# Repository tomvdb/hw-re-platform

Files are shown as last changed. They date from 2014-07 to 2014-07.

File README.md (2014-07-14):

Hardware Reverse Engineering Learning Platform
==============================================

Current Status:

2014/07/17: Boards received, concept works, pcb has some minor issues. Working on v2
2014/06/20: PCB's sent for manufacturing - Not Tested Yet

I enjoy trying to reverse engineer the famous crackme and reverseme executables in my spare time. After reading the xbox reverse engineering book by bunnie I went looking at the my options for learning and experimenting with hardware reverse engineering. Unfortunately the options are few and expensive.

The hardware reverse engineering platform is basically a shield for the new stm32 nucleo boards using the st-morpho connectors. It contains two arduino compatible microcontrollers and an eeprom. There are 8 data lines connected between the two microcontrollers and there is also i2c lines connecting the mcu's with an eeprom. The nucleo board handles loading the reverse engineering scenario on the shield (firmware on the avr's and data on the eeprom). Test pins are added on all the data lines for connection to RE tools. This allows anyone to easily create firmware that depicts a possible RE situation. For example the two mcu's can communicate with each other using a certain protocol.

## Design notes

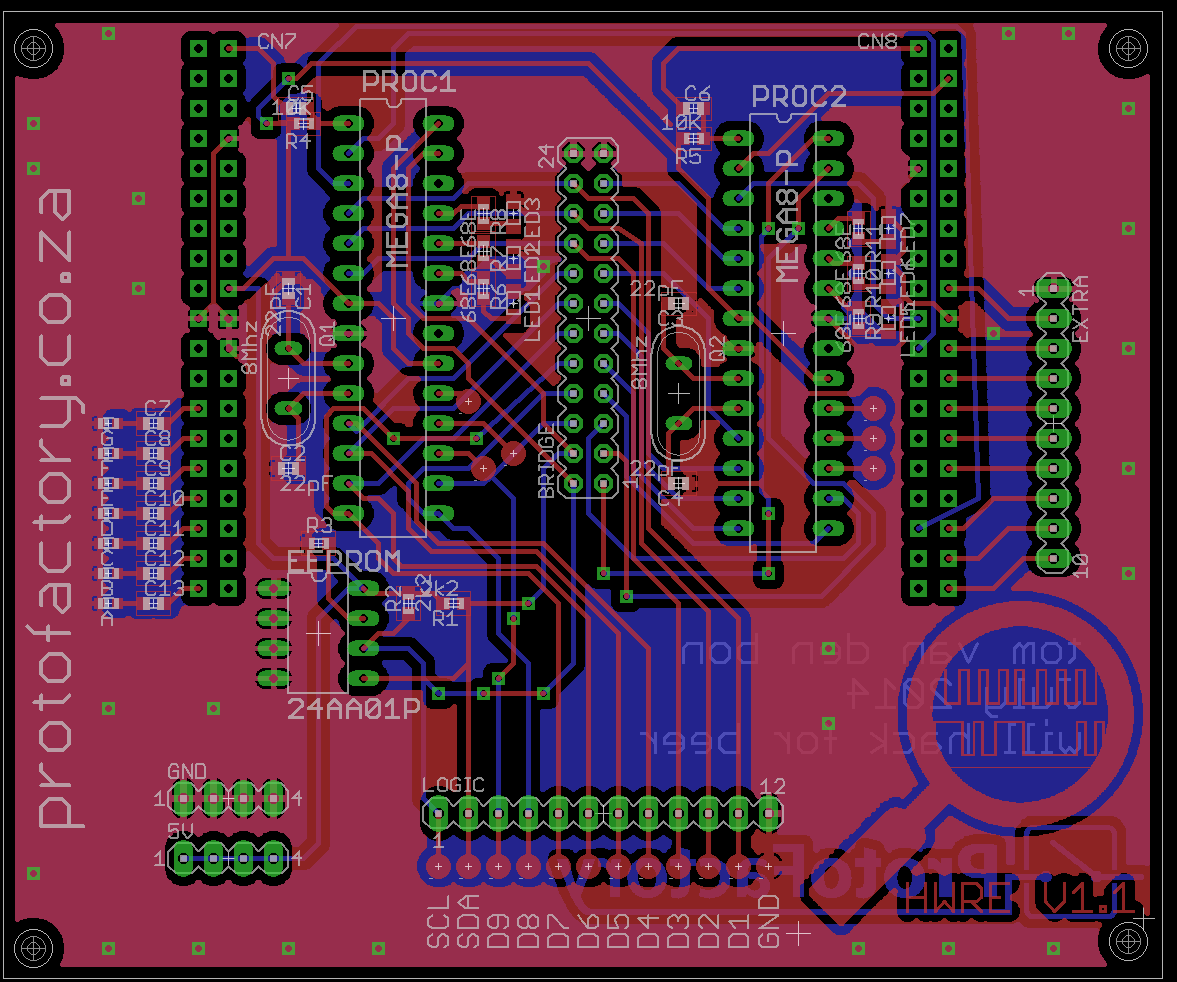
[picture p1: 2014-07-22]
hwre1.1preview_eagle.png

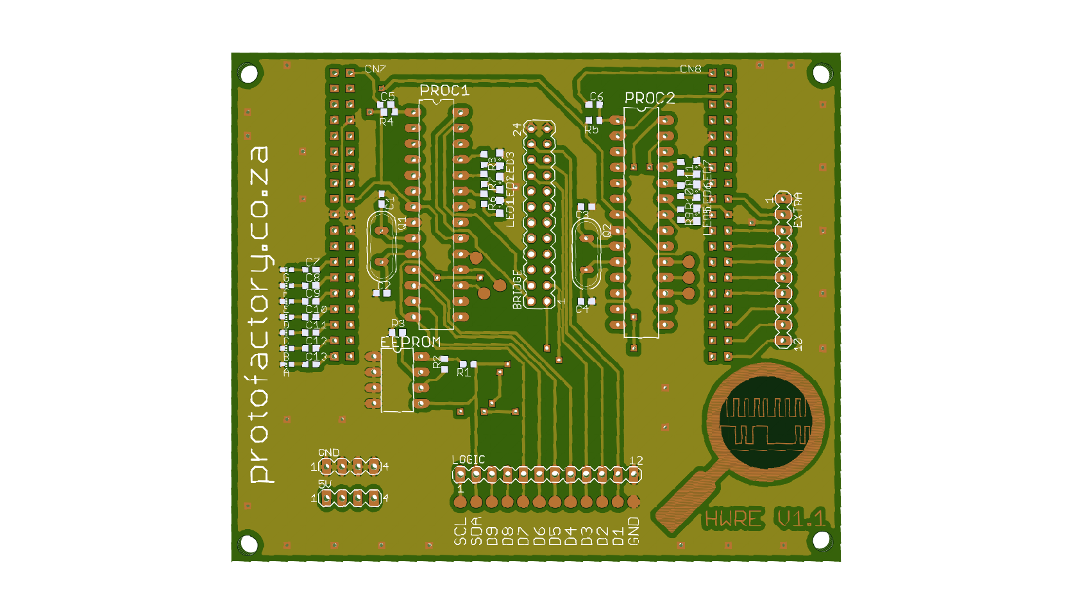
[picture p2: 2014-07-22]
hwre1.1preview.png

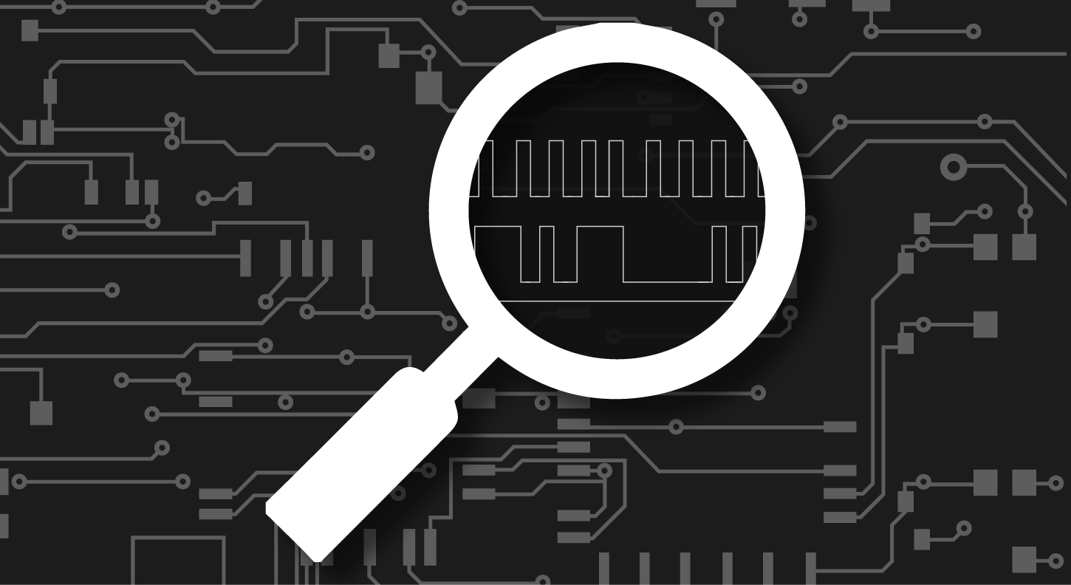
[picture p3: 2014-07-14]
documentation/resources/circuit_1-01.png

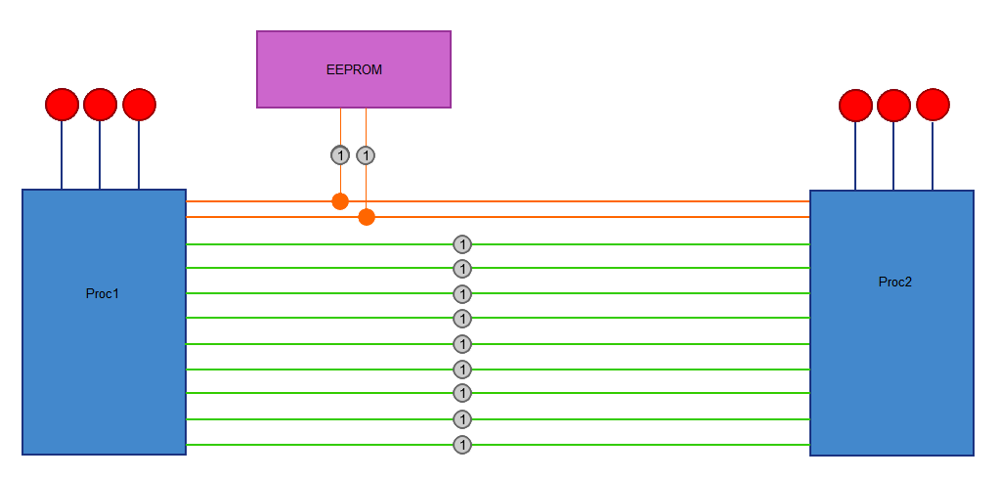
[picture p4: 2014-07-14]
documentation/resources/boarddiagram.png

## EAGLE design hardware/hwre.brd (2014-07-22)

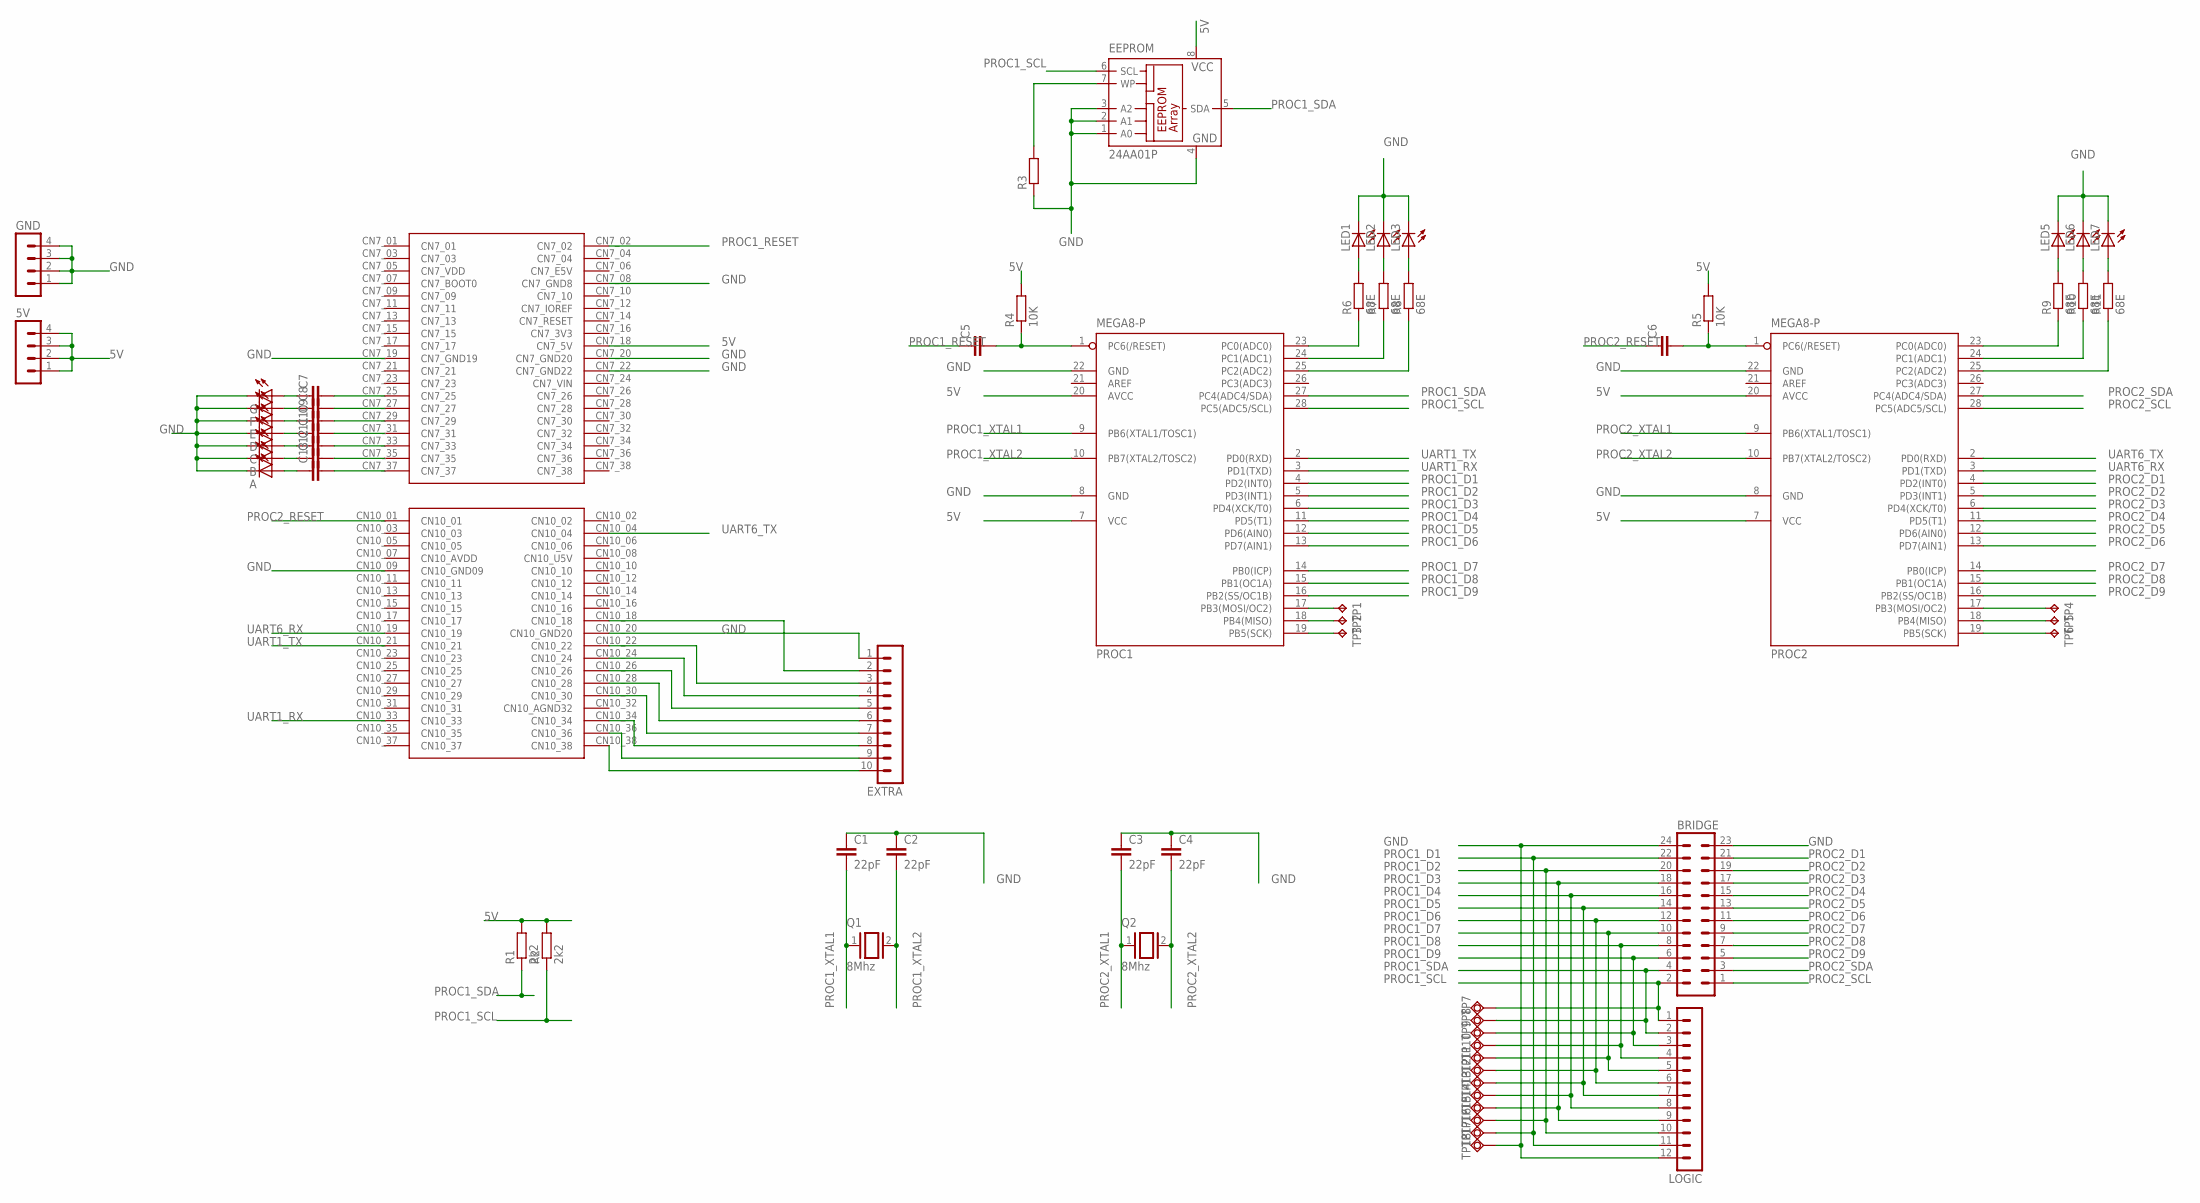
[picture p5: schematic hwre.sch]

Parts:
5V: MA04-1
A: LEDCHIP-LED0603; CHIP-LED0603
B: LEDCHIP-LED0603; CHIP-LED0603
BRIDGE: MA12-2
C: LEDCHIP-LED0603; CHIP-LED0603
C1, C2, C3, C4: 22pF; C0603
C5, C6, C7, C8, C9, C10, C11, C12, C13: C-EUC0603; C0603
D: LEDCHIP-LED0603; CHIP-LED0603
E: LEDCHIP-LED0603; CHIP-LED0603
EEPROM: 24AA01P; DIL8
EXTRA: MA10-1
F: LEDCHIP-LED0603; CHIP-LED0603
G: LEDCHIP-LED0603; CHIP-LED0603
GND: MA04-1
LED1, LED2, LED3, LED5, LED6, LED7: LEDSML0805; SML0805
LOGIC: MA12-1
PROC1, PROC2: MEGA8-P; DIL28-3
Q1, Q2: 8Mhz; QS
R1, R2: 2k2; R0603
R3: R-EU_R0603; R0603
R4, R5: 10K; R0603
R6, R7, R8, R9, R10, R11: 68E; R0603
TP1, TP2, TP3, TP4, TP5, TP6: TPTP20R; TP20R
TP7, TP8, TP9, TP10, TP11, TP12, TP13, TP14, TP15, TP16, TP17, TP18: TPSQTP20R; TP20R
U$1: NUCLEO_SHIELDGENERIC; NUCLEO_SHIELD

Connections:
5V: 5V.1, 5V.2, 5V.3, 5V.4, EEPROM.8 (VCC), PROC1.7 (VCC), PROC1.20 (AVCC), PROC2.7 (VCC), PROC2.20 (AVCC), R1.2, R2.2, R4.2, R5.2, U$1.CN7_18 (CN7_5V)
GND: A.C, B.C, BRIDGE.23, BRIDGE.24, C.C, C1.1, C2.1, C3.1, C4.1, D.C, E.C, EEPROM.1 (A0), EEPROM.2 (A1), EEPROM.3 (A2), EEPROM.4 (GND), EXTRA.1, F.C, G.C, GND.1, GND.2, GND.3, GND.4, LED1.C, LED2.C, LED3.C, LED5.C, LED6.C, LED7.C, LOGIC.12, PROC1.8 (GND), PROC1.22 (GND), PROC2.8 (GND), PROC2.22 (GND), R3.1, TP18.TP, U$1.CN7_08 (CN7_GND8), U$1.CN7_19 (CN7_GND19), U$1.CN7_20 (CN7_GND20), U$1.CN7_22 (CN7_GND22), U$1.CN10_09 (CN10_GND09), U$1.CN10_20 (CN10_GND20)
unnamed: PROC1.23 (PC0(ADC0)), R6.1
unnamed: PROC1.24 (PC1(ADC1)), R7.1
unnamed: PROC1.25 (PC2(ADC2)), R8.1
unnamed: LED1.A, R6.2
unnamed: LED2.A, R7.2
unnamed: EEPROM.7 (WP), R3.2
unnamed: LED3.A, R8.2
unnamed: PROC1.17 (PB3(MOSI/OC2)), TP1.TP
unnamed: PROC2.23 (PC0(ADC0)), R9.1
unnamed: PROC2.24 (PC1(ADC1)), R10.1
unnamed: PROC2.25 (PC2(ADC2)), R11.1
unnamed: LED5.A, R9.2
unnamed: LED6.A, R10.2
unnamed: LED7.A, R11.2
unnamed: PROC1.18 (PB4(MISO)), TP2.TP
unnamed: PROC1.19 (PB5(SCK)), TP3.TP
unnamed: PROC2.17 (PB3(MOSI/OC2)), TP4.TP
unnamed: PROC2.18 (PB4(MISO)), TP5.TP
unnamed: PROC2.19 (PB5(SCK)), TP6.TP
unnamed: C7.2, U$1.CN7_25
unnamed: C8.2, U$1.CN7_27
unnamed: C9.2, U$1.CN7_29
unnamed: C10.2, U$1.CN7_31
unnamed: C11.2, U$1.CN7_33
unnamed: C12.2, U$1.CN7_35
unnamed: C13.2, U$1.CN7_37
unnamed: C7.1, G.A
unnamed: C8.1, F.A
unnamed: C9.1, E.A
unnamed: C10.1, D.A
unnamed: C.A, C11.1
unnamed: B.A, C12.1
unnamed: A.A, C13.1
unnamed: EXTRA.10, U$1.CN10_38
unnamed: EXTRA.9, U$1.CN10_36
unnamed: EXTRA.8, U$1.CN10_34
unnamed: EXTRA.7, U$1.CN10_30
unnamed: EXTRA.6, U$1.CN10_28
unnamed: EXTRA.5, U$1.CN10_26
unnamed: EXTRA.4, U$1.CN10_24
unnamed: EXTRA.3, U$1.CN10_22
unnamed: EXTRA.2, U$1.CN10_18
PC6: C5.2, PROC1.1 (PC6(/RESET)), R4.1
PROC1_D1: BRIDGE.22, LOGIC.11, PROC1.4 (PD2(INT0)), TP17.TP
PROC1_D2: BRIDGE.20, LOGIC.10, PROC1.5 (PD3(INT1)), TP16.TP
PROC1_D3: BRIDGE.18, LOGIC.9, PROC1.6 (PD4(XCK/T0)), TP15.TP
PROC1_D4: BRIDGE.16, LOGIC.8, PROC1.11 (PD5(T1)), TP14.TP
PROC1_D5: BRIDGE.14, LOGIC.7, PROC1.12 (PD6(AIN0)), TP13.TP
PROC1_D6: BRIDGE.12, LOGIC.6, PROC1.13 (PD7(AIN1)), TP12.TP
PROC1_D7: BRIDGE.10, LOGIC.5, PROC1.14 (PB0(ICP)), TP11.TP
PROC1_D8: BRIDGE.8, LOGIC.4, PROC1.15 (PB1(OC1A)), TP10.TP
PROC1_D9: BRIDGE.6, LOGIC.3, PROC1.16 (PB2(SS/OC1B)), TP9.TP
PROC1_RESET: C5.1, U$1.CN7_02
PROC1_SCL: BRIDGE.2, EEPROM.6 (SCL), LOGIC.1, PROC1.28 (PC5(ADC5/SCL)), R2.1, TP7.TP
PROC1_SDA: BRIDGE.4, EEPROM.5 (SDA), LOGIC.2, PROC1.27 (PC4(ADC4/SDA)), R1.1, TP8.TP
PROC1_XTAL1: C1.2, PROC1.9 (PB6(XTAL1/TOSC1)), Q1.1
PROC1_XTAL2: C2.2, PROC1.10 (PB7(XTAL2/TOSC2)), Q1.2
PROC2_D1: BRIDGE.21, PROC2.4 (PD2(INT0))
PROC2_D2: BRIDGE.19, PROC2.5 (PD3(INT1))
PROC2_D3: BRIDGE.17, PROC2.6 (PD4(XCK/T0))
PROC2_D4: BRIDGE.15, PROC2.11 (PD5(T1))
PROC2_D5: BRIDGE.13, PROC2.12 (PD6(AIN0))
PROC2_D6: BRIDGE.11, PROC2.13 (PD7(AIN1))
PROC2_D7: BRIDGE.9, PROC2.14 (PB0(ICP))
PROC2_D8: BRIDGE.7, PROC2.15 (PB1(OC1A))
PROC2_D9: BRIDGE.5, PROC2.16 (PB2(SS/OC1B))
PROC2_PC6: C6.2, PROC2.1 (PC6(/RESET)), R5.1
PROC2_RESET: C6.1, U$1.CN10_01
PROC2_SCL: BRIDGE.1, PROC2.28 (PC5(ADC5/SCL))
PROC2_SDA: BRIDGE.3, PROC2.27 (PC4(ADC4/SDA))
PROC2_XTAL1: C3.2, PROC2.9 (PB6(XTAL1/TOSC1)), Q2.1
PROC2_XTAL2: C4.2, PROC2.10 (PB7(XTAL2/TOSC2)), Q2.2
UART1_RX: PROC1.3 (PD1(TXD)), U$1.CN10_33
UART1_TX: PROC1.2 (PD0(RXD)), U$1.CN10_21
UART6_RX: PROC2.3 (PD1(TXD)), U$1.CN10_19
UART6_TX: PROC2.2 (PD0(RXD)), U$1.CN10_04

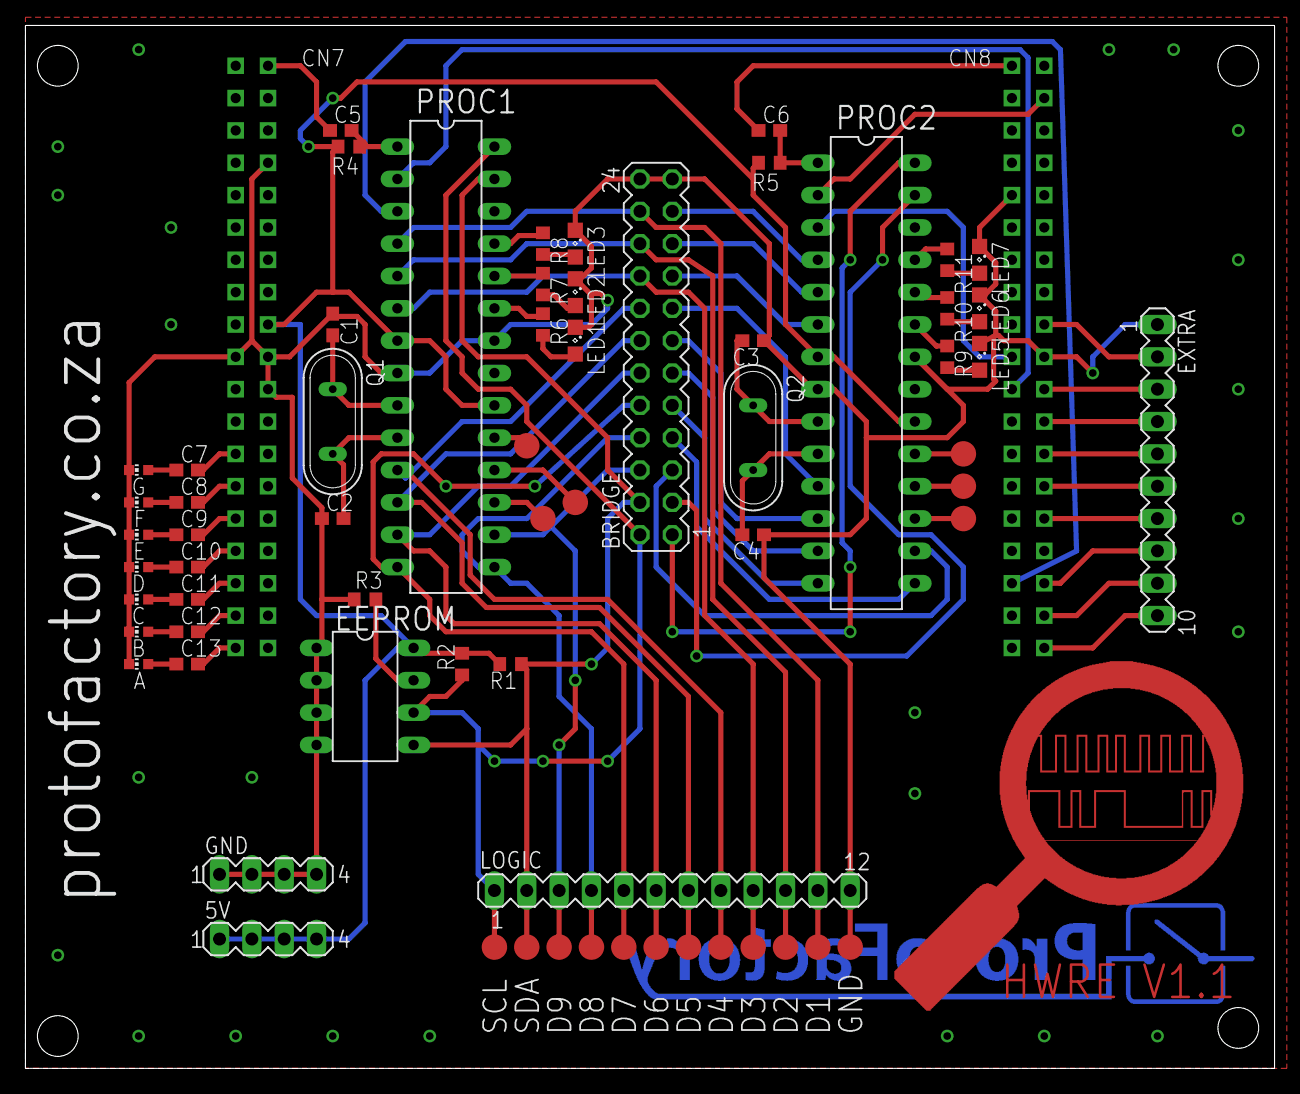
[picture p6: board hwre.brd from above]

Board: 2 copper layers, 98.1 x 81.9 mm, 68 parts (1 on the bottom side), 78 nets.

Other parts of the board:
U$2: HWRE
U$3: LOGO
